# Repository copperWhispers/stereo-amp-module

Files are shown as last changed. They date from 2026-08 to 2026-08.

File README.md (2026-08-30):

# STEREO AMP MODULE

An open-source stereo class-D amplifier board built around the TI TPA3116D2. Full KiCad source, gerbers, and a BOM.
Link to TPA3116D2 Part: https://www.ti.com/lit/ds/symlink/tpa3118d2.pdf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
This is an interesting part with many different configurations which can handle 4 ohms and 8 ohms Stereo Speakers at various Power ratings:


**Here is an image of the PCB I designed for it:**



---

## What it is

| | |
|---|---|
| **Amplifier** | TPA3116D2DADR — class-D, stereo, BTL |
| **Configuration** | Master mode, 26 dB gain, differential inputs |
| **Supply** | 4.5–20 V (built and tested at 12 V) Could go to 26V with different caps.|
| **Output** | ~18 W into 4 Ω, limited by the 12 V rail |
| **Idle current** | ~50 mA at 12 V |
| **Assembly** | Hand-solderable — 0603 passives, HTSSOP-32|

An interactive BOM is included at [`docs/ibom.html`](docs/ibom.html) — open it in a browser and it highlights each part on the board as you work through the build.

---

## Build it

BOM: Open docs/ibom.html in a browser.

**Boards:** order `production/gerbers.zip` from JLCPCB or PCBWay, or build the boards yourself.

**Schematic:** [`docs/schematic.pdf`](docs/schematic.pdf) · **Board:** [`docs/pcb.pdf`](docs/pcb.pdf)

## Errata — v1 needs two wire links

As the board is single layer as I am building it using a UV, photosensitive film and copper clad board method, thus external connections have to be made via wires, I have placed pads on the layout to make the soldering process easier:

**Wire link between these pads:**



**Solder bridge across these legs:**



---

## Extras

**GAIN**

Going in, I expected to set the gain to whatever the maths called for, pick a resistor ratio, get that gain. The TPA3116D2 doesn't work that way. It offers four fixed settings: 20, 26, 32 and 36 dB selected by a voltage divider on the GAIN/SLV pin. The setting latches at power-up and can't be changed while running. 
I will thus be modulating the volume via a later preamp module that will also serve as an inputs mixer, I will probably add a couple of other fun features on there too, and it will allow me to protect the input of the audio amplifier by ensuring that signals get attenuating to the right scale before going in.

This board ended up at **26 dB** (20 kΩ to GND, 100 kΩ to GVDD). Which if we use the equation  dB = 20 * Log(Gain)  then rearrange for Gain ->  Gain = 10^(dB/20) we get Gain = 19.95.

However as I show in the video there are many other settings that you can configure this gain to and this can be achieved simply by changing the GAIN/SLV resistor values:



**BTL vs SLV**

**Speakers Safety:** 

the speakers are never at risk. On a 12 V rail the maximum output is about 18 W into 4 Ω, and the speakers are rated 20 W. The supply voltage is the protection, the amplifier physically cannot deliver enough power to damage them, whatever you do with the volume knob.

---

## Video

[https://youtu.be/IWhPQ7ZQIiU](https://youtu.be/IWhPQ7ZQliU?si=qsnklUcxvsyva8gy)

## Licence

**CERN-OHL-S v2** for hardware, **CC BY-SA 4.0** for documentation — see `LICENSE`.

Build it, modify it, sell it. If you distribute a modified design, that design has to be open too.

---

Built one? Open an issue with a photo — I'd like to see it.

New board every month: [copperWhispers](https://copperwhispers.com)

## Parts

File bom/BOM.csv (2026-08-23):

Ref | Qty | Value | Package | Spec | Critical | Notes
U1 | 1 | TPA3116D2DADR | HTSSOP-32 | TI class-D stereo amplifier | YES | No substitute
L1,L2,L3,L4 | 4 | 11uH | Axial D4.5mm P15.24mm | Isat >= 4A, DCR < 50mR | YES | Output filter. Saturation rating matters more than the inductance — at 18W into 4R peak current is ~3A
C32,C33,C34,C35 | 4 | 1.5uF | 0805 | 50V X7R | YES | Output filter. Board was built with 1.4uF; 1.5uF is the stock value and gives fc = 39kHz with 11uH. Use 0805 not 0603 — 0603 loses most of its capacitance under DC bias
C21,C28,C39,C40,C41,C42 | 6 | 1nF | 0603 | 50V C0G/NP0 |  | Snubbers — C0G rather than X7R, dielectric losses work against what a snubber does
R28,R29,R30,R31,R32 | 5 | 3.3R | 0805 | 1/8W 1% |  | Snubbers — 0805 rather than 0603 for the power rating
R25,R26,R27 | 3 | 100k | 0603 | 1% |  | Gain network — 1% matters, this divider selects the gain mode
R24 | 1 | 20k | 0603 | 1% |  | Gain network — 1% matters, this divider selects the gain mode
C24,C25,C26,C27 | 4 | 220nF | 0603 | 50V X7R |  | Bootstrap
C14,C36,C37,C38,C43 | 5 | 10nF | 0603 | 50V X7R
C17,C18,C19 | 3 | 1uF | 0603 | 50V X7R
C20,C22,C29 | 3 | 100nF | 0603 | 50V X7R |  | Decoupling
C23,C30 | 2 | 220uF | Axial D5mm P18mm | 25V electrolytic low-ESR |  | Bulk on the 12V rail
C15,C16 | 2 | 10uF | Axial D5mm P18mm | 25V electrolytic

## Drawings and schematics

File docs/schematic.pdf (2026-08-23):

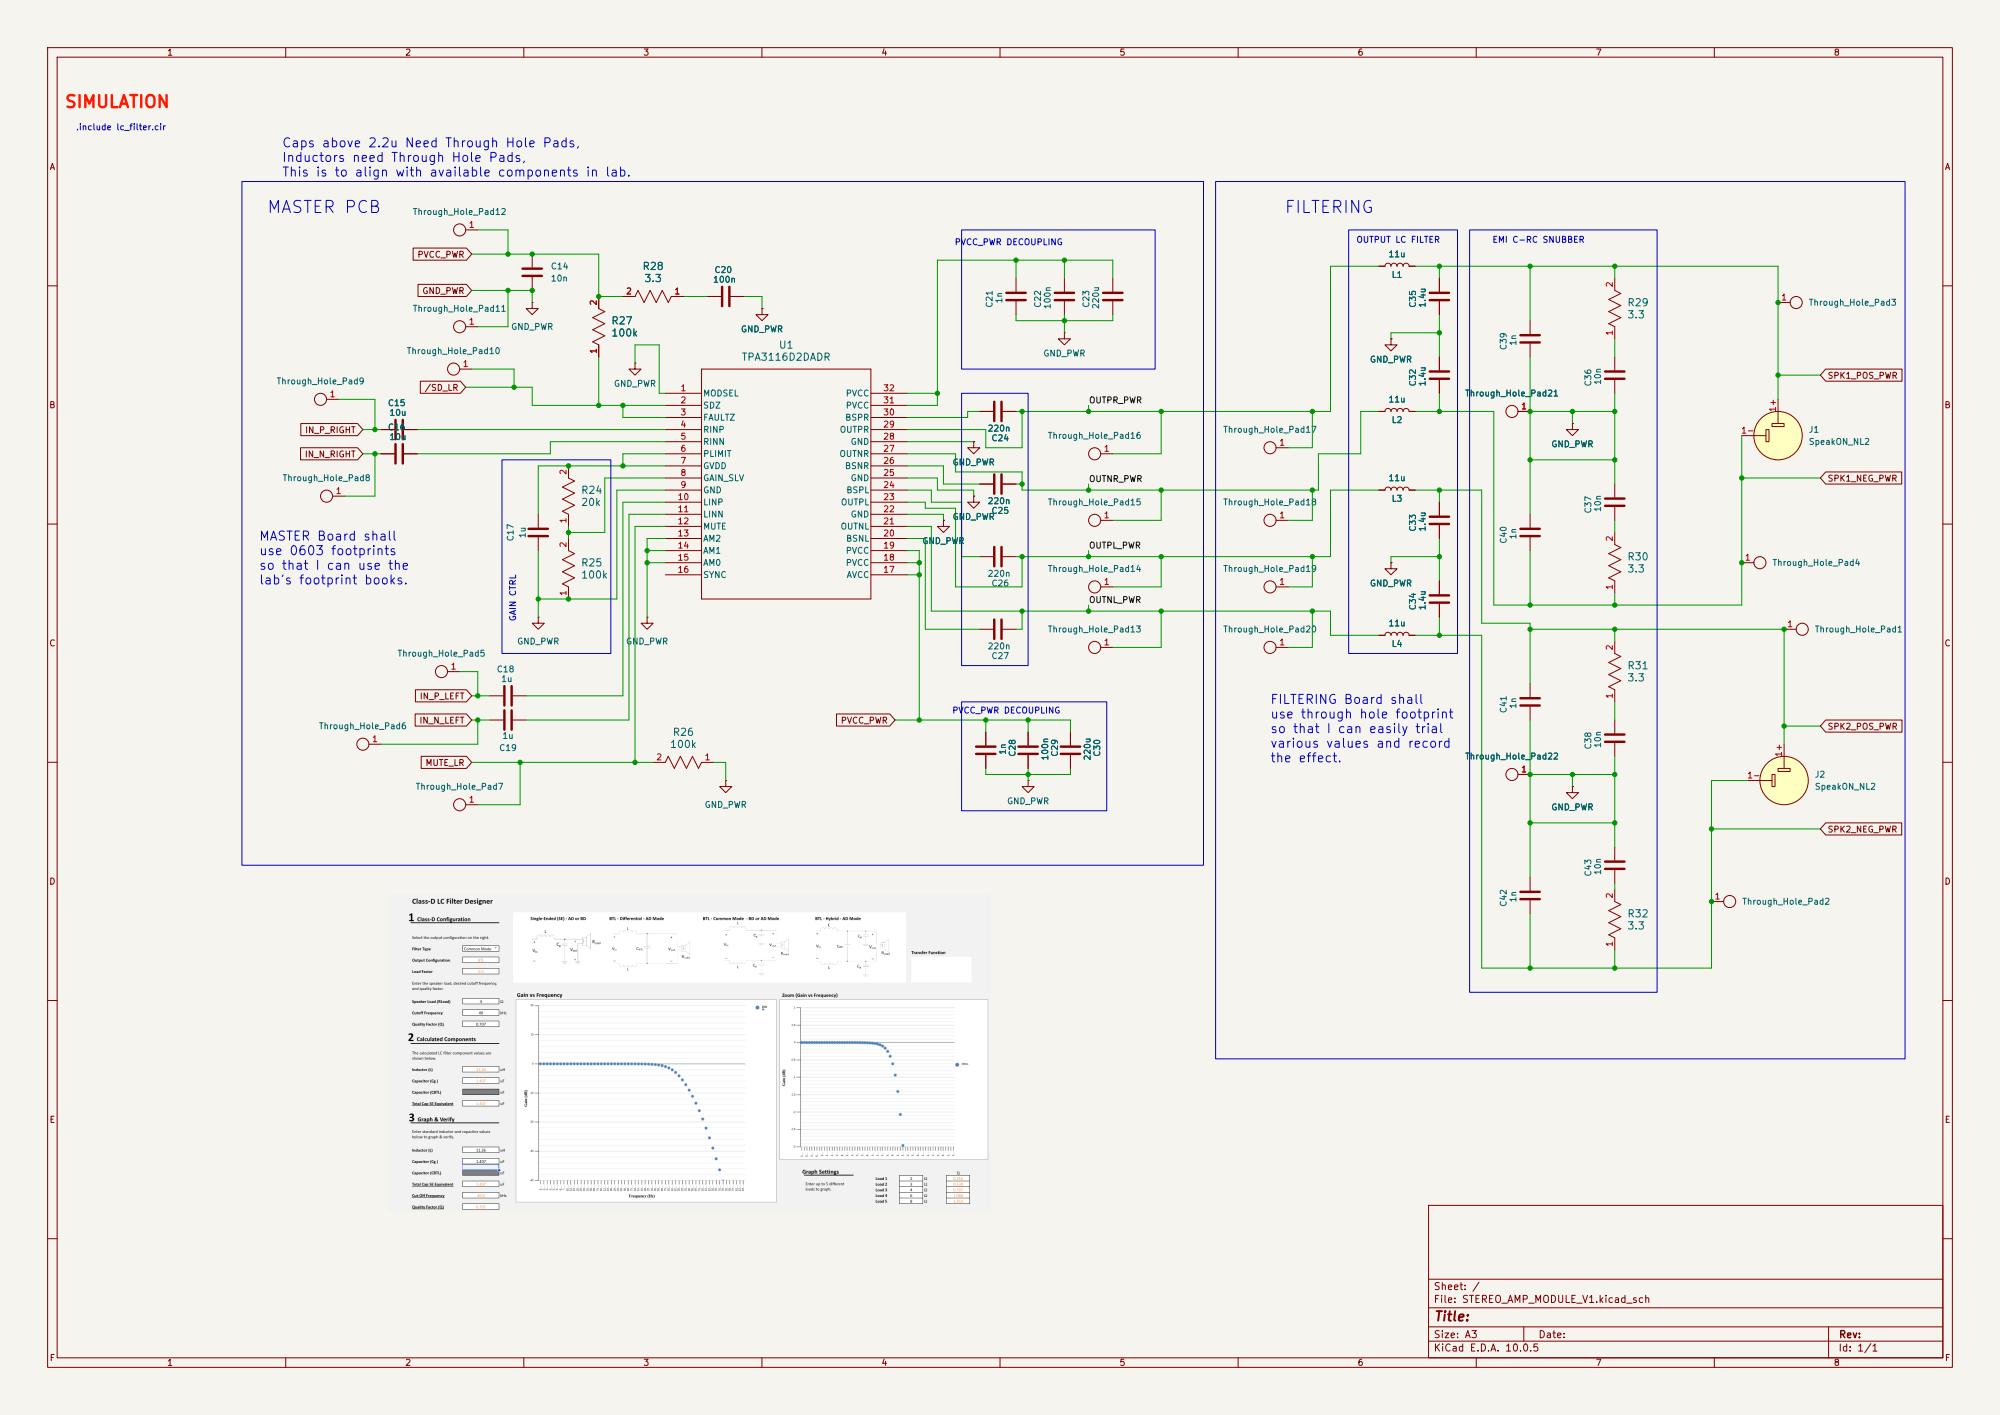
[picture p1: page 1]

Caps above 2.2u Need Through Hole Pads,
Inductors need Through Hole Pads,
This is to align with available components in lab.

OUTPUT LC FILTER FILTERING
11u C35 1.4u GND_PWR C32 1.4u

LINP 10 | | 11u C24

Through_Hole_Pad17

MASTER Board shall use 0603 footprints

so that I can use the
lab's footprint books.

Through_Hole_Pad19

FILTERING Board shall use through hole footprint so that I can easily trial

various values and record
the effect.

Size: A3 | Rev: | F Date:
KiCad E.D.A. 10.0.5 | Id: 1/1

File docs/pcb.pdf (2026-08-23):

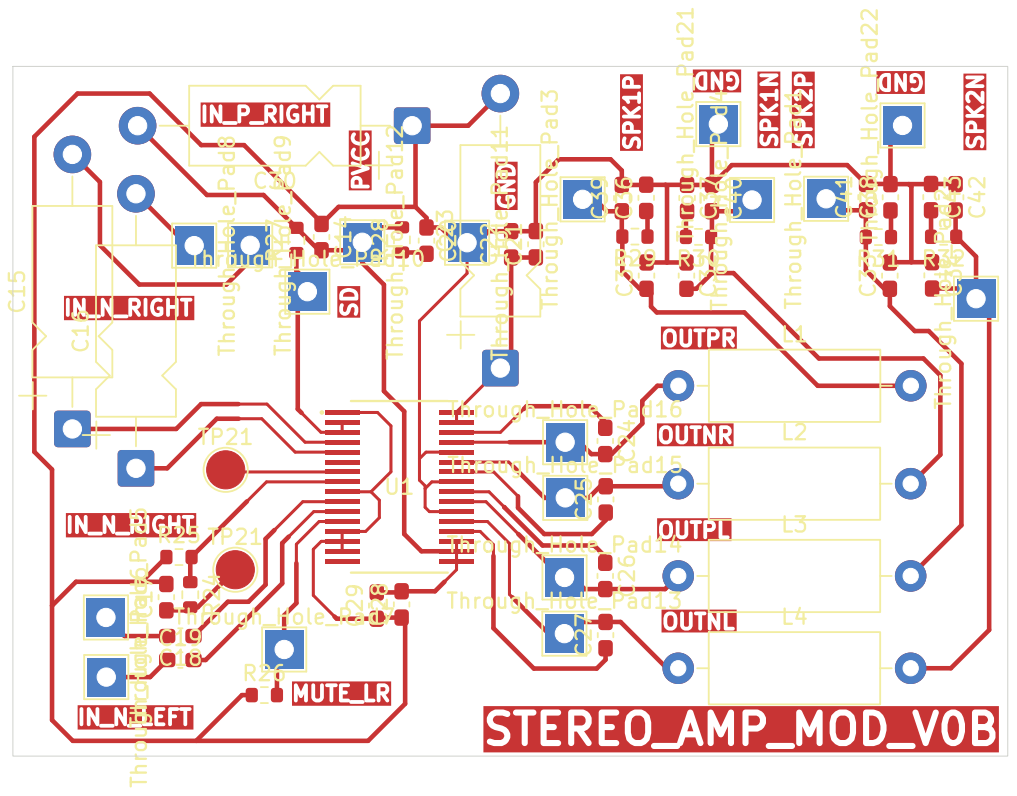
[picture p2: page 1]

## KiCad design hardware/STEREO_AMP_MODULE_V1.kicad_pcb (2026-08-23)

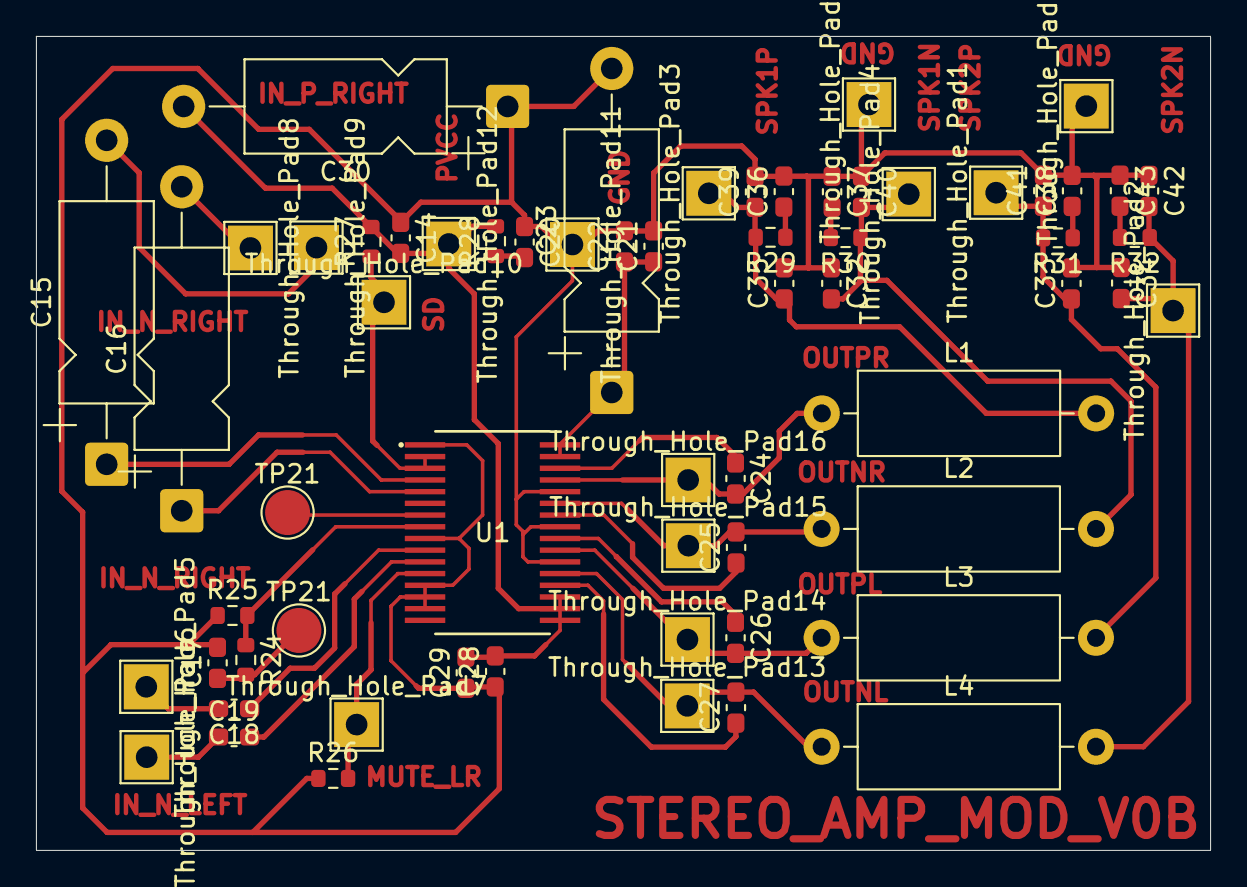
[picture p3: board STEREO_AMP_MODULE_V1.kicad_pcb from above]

Board: 2 copper layers, 65.2 x 45.2 mm, 63 parts (0 on the bottom side), 32 nets.

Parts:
C14, C36, C37, C38, C43: 10n; C_0603_1608Metric_Pad1.08x0.95mm_HandSolder
C15, C16: 10u; CP_Axial_L11.0mm_D5.0mm_P18.00mm_Horizontal
C17, C18, C19: 1u; C_0603_1608Metric_Pad1.08x0.95mm_HandSolder
C20, C22, C29: 100n; C_0603_1608Metric_Pad1.08x0.95mm_HandSolder
C21, C28, C39, C40, C41, C42: 1n; C_0603_1608Metric_Pad1.08x0.95mm_HandSolder
C23, C30: 220u; CP_Axial_L11.0mm_D5.0mm_P18.00mm_Horizontal
C24, C25, C26, C27: 220n; C_0603_1608Metric_Pad1.08x0.95mm_HandSolder
C32, C33, C34, C35: 1.4u; C_0603_1608Metric_Pad1.08x0.95mm_HandSolder
L1, L2, L3, L4: 11u; L_Axial_L11.0mm_D4.5mm_P15.24mm_Horizontal_Fastron_MECC
R24: 20k; R_0603_1608Metric
R25, R26, R27: 100k; R_0603_1608Metric
R28, R29, R30, R31, R32: 3.3; R_0603_1608Metric
TP21, TP21#2: TestPoint; TestPoint_Pad_D2.5mm
Through_Hole_Pad1, Through_Hole_Pad2, Through_Hole_Pad3, Through_Hole_Pad4, Through_Hole_Pad5, Through_Hole_Pad6, Through_Hole_Pad7, Through_Hole_Pad8, Through_Hole_Pad9, Through_Hole_Pad10, Through_Hole_Pad11, Through_Hole_Pad12, Through_Hole_Pad13, Through_Hole_Pad14, Through_Hole_Pad15, Through_Hole_Pad16, Through_Hole_Pad21, Through_Hole_Pad22: TestPoint_THTPad_2.5x2.5mm_Drill1.2mm
U1: TPA3116D2DADR; DAD0032A_L

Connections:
/OUTNL_PWR: C27.2, L4.1, Through_Hole_Pad13.1, U1.21 (OUTNL)
/OUTNR_PWR: C25.2, L2.1, Through_Hole_Pad15.1, U1.27 (OUTNR)
/OUTPL_PWR: C26.2, L3.1, Through_Hole_Pad14.1, U1.23 (OUTPL)
/OUTPR_PWR: C24.2, L1.1, Through_Hole_Pad16.1, U1.29 (OUTPR)
GND_PWR: C14.1, C17.2, C20.1, C21.2, C22.2, C23.2, C28.1, C29.1, C30.1, C32.1, C33.2, C34.1, C35.2, C36.2, C37.1, C38.2, C39.2, C40.1, C41.2, C42.1, C43.1, R25.1, R26.1, Through_Hole_Pad11.1, Through_Hole_Pad21.1, Through_Hole_Pad22.1, U1.1 (MODSEL), U1.9 (GND), U1.13 (AM2), U1.14 (AM1), U1.15 (AM0), U1.22 (GND), U1.25 (GND), U1.28 (GND)
IN_N_LEFT: C19.1, Through_Hole_Pad6.1
IN_N_RIGHT: C16.2, Through_Hole_Pad8.1
IN_P_LEFT: C18.2, Through_Hole_Pad5.1
IN_P_RIGHT: C15.2, Through_Hole_Pad9.1
MUTE_LR: R26.2, Through_Hole_Pad7.1, U1.12 (MUTE)
unnamed: C20.2, R28.1
unnamed: C21.1, C22.1, C23.1, U1.31 (PVCC), U1.32 (PVCC)
unnamed: C36.1, R29.1
unnamed: C37.2, R30.2
unnamed: C38.1, R31.1
unnamed: C43.2, R32.2
unnamed: C27.1, U1.20 (BSNL)
unnamed: C25.1, U1.26 (BSNR)
unnamed: C26.1, U1.24 (BSPL)
unnamed: C24.1, U1.30 (BSPR)
unnamed: R24.1, R25.2, U1.8 (GAIN_SLV)
unnamed: C17.1, R24.2, TP21.1 (1_1), TP21#2.1 (1_1), U1.6 (PLIMIT), U1.7 (GVDD)
unnamed: C19.2, U1.11 (LINN)
unnamed: C18.1, U1.10 (LINP)
unnamed: C16.1, U1.5 (RINN)
unnamed: C15.1, U1.4 (RINP)
PVCC_PWR: C14.2, C28.2, C29.2, C30.2, R27.2, R28.2, Through_Hole_Pad12.1, U1.17 (AVCC), U1.18 (PVCC), U1.19 (PVCC)
SPK1_NEG_PWR: C32.2, C40.2, L2.2, R30.1, Through_Hole_Pad4.1
SPK1_POS_PWR: C35.1, C39.1, L1.2, R29.2, Through_Hole_Pad3.1
SPK2_NEG_PWR: C34.2, C42.2, L4.2, R32.1, Through_Hole_Pad2.1
SPK2_POS_PWR: C33.1, C41.1, L3.2, R31.2, Through_Hole_Pad1.1
/SD_LR: R27.1, Through_Hole_Pad10.1, U1.2 (SDZ), U1.3 (FAULTZ)

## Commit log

2026-08-23 STEREO_AMP_MODULE — initial open-source release
    [BOM.csv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]
2026-08-23 BOM: specs over part numbers
    [BOM.csv]
2026-08-23 BOM Readme
